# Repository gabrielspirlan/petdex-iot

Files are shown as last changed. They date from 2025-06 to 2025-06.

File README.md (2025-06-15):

<p align="center">
  Capa do Projeto
</p>

# Projeto IoT — Coleira Inteligente para Monitoramento de Animais

Bem-vindo! Este é o nosso projeto de Internet das Coisas (IoT), desenvolvido com o objetivo de criar um dispositivo inteligente que possa ser acoplado a qualquer coleira de animal — especialmente cães 🐶 e gatos 😺 — para monitorar continuamente dados de saúde e localização do pet, de forma semelhante às smartbands e smartwatches ⌚ utilizados por humanos.

<p align="center">
  Coleira PetDex
</p>

<p align="center">
  Coleira PetDex - 2
  Coleira PetDex - 3
</p>

## 🚩 Problema Identificado

Atualmente, existe uma carência de soluções acessíveis e contínuas para monitoramento de saúde em animais domésticos, especialmente aqueles que possuem doenças crônicas ou estão em tratamento. Além disso, muitos tutores enfrentam dificuldades ao perder seus pets e não conseguirem localizá-los facilmente.

## 💡 Solução Proposta

Criamos uma coleira inteligente equipada com sensores capazes de coletar dados vitais e de movimentação do animal. Através desses dados, conseguimos monitorar:

- **Batimentos cardíacos**
- **Nível de atividade física**
- **Localização em tempo real**

Com isso, é possível detectar comportamentos anormais e enviar alertas ao tutor caso o batimento cardíaco do animal esteja fora da faixa considerada normal, especialmente em relação ao seu nível de movimentação.

Todos os dados coletados são enviados automaticamente para um banco de dados via uma API que desenvolvemos, permitindo o acompanhamento em tempo real.

## 📦 Componentes Utilizados

- **ESP32 S3 Zero**: Microcontrolador com conectividade Wi-Fi e Bluetooth, ideal pelo seu tamanho compacto.
- **GY-MAX30102**: Sensor de batimentos cardíacos e oxímetro.
- **MPU6050**: Sensor de giroscópio e acelerômetro, responsável por captar a movimentação do animal.
- **NEO-6M**: Módulo GPS para rastreamento em tempo real.
- **LED RGB**: Indicadores visuais de status da coleira.

<p align="center">
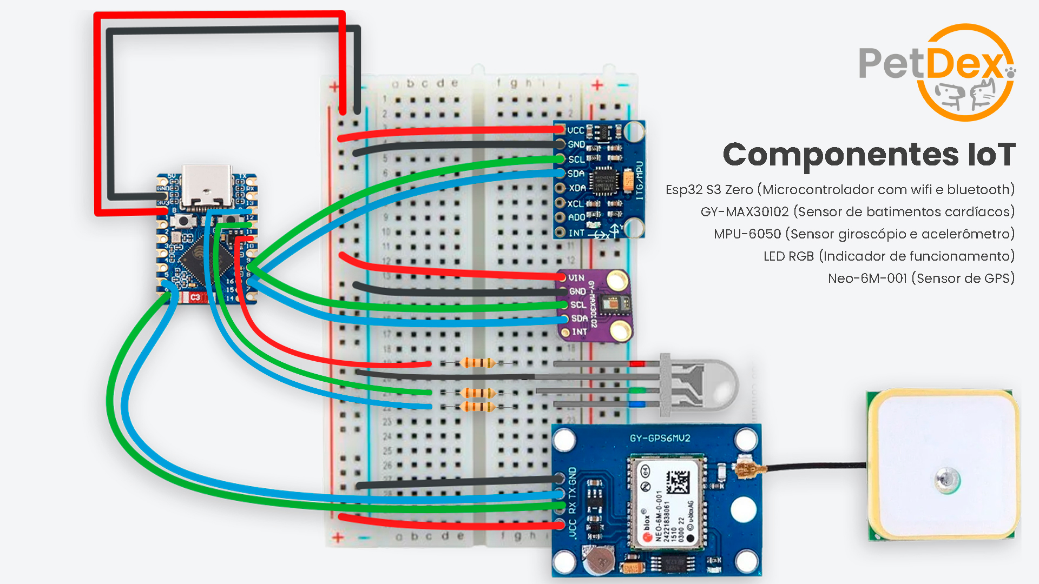
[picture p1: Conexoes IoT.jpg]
Conexões do IoT
  
</p>

## 🔧 Funcionamento dos LED indicador

- **LED Azul**: Tentativa de conexão com a rede Wi-Fi.
- **LED Verde**: Dados coletados com sucesso e enviados ao banco de dados.
- **LED Vermelho**:
  - Se acender após o LED azul: falha na conexão com o sensor de batimentos cardíacos.
  - Se acender rapidamente depois: falha no envio dos dados ao servidor.
- **LED Branco**: Falha na obtenção da hora atual. Nesse caso, recomenda-se reiniciar a coleira.

## 🧩 Projeto 3D

Também desenvolvemos um **suporte 3D personalizado** para fixar o circuito à coleira do animal de forma segura, confortável e discreta. O suporte foi projetado levando em consideração o bem-estar do pet e a praticidade de uso.

---

## 🤖 Programação

A programação do dispositivo foi feita utilizando a **IDE do Arduino**, com foco na simplicidade e eficiência.

Todo o funcionamento está concentrado em um único arquivo principal, localizado na pasta [`/code`](./code), onde o usuário pode configurar previamente as redes Wi-Fi às quais a coleira deve tentar se conectar.

### Funcionamento Geral do Código

- Ao iniciar, a coleira tenta se conectar automaticamente a uma das redes Wi-Fi configuradas.
- Após o sucesso da conexão, o sistema realiza a leitura dos **batimentos cardíacos** do animal por cerca de **15 segundos**, calculando uma **média** dos valores coletados.
- Em seguida, os dados de:
  - **Batimentos cardíacos**
  - **Movimentação** (acelerômetro e giroscópio)
  - **Localização GPS**

  são enviados para o **endpoint da nossa API** por meio de uma requisição HTTP.

Essa estrutura permite que os dados sejam atualizados em tempo real no banco de dados, possibilitando o monitoramento remoto da saúde e localização do animal.

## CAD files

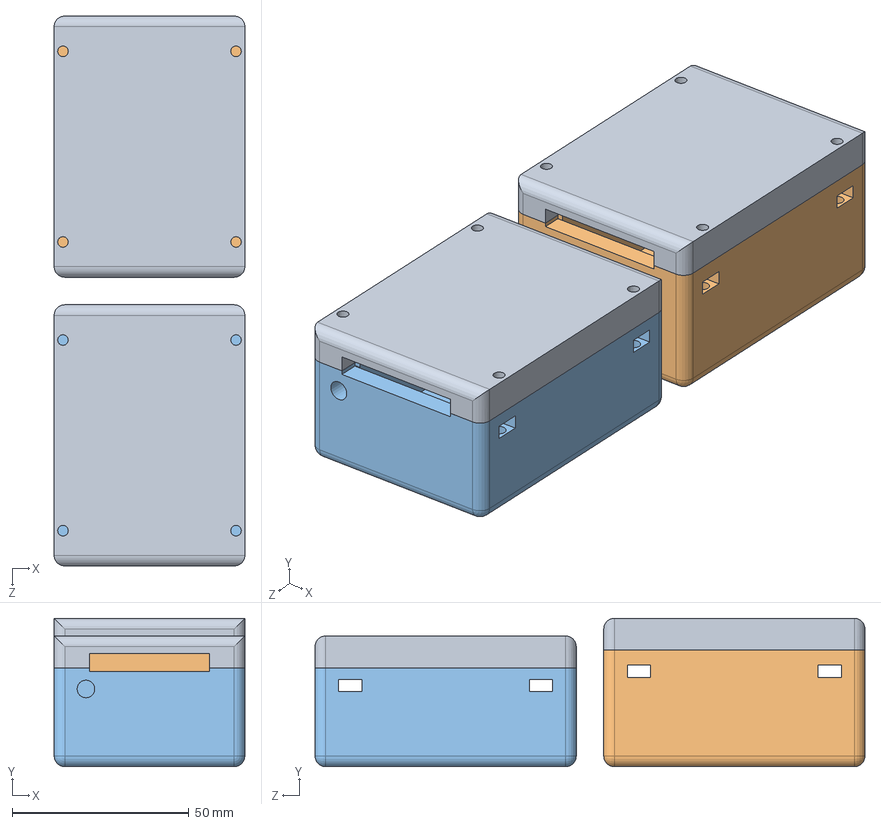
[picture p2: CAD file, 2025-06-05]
projeto-coleira/Montagem versões da coleira.SLDASM
54.0 x 42.0 x 155.8 mm
Coleira - Sensores (Ajustado v2)
Coleira - Sensores
Coleira - Tampa x 2

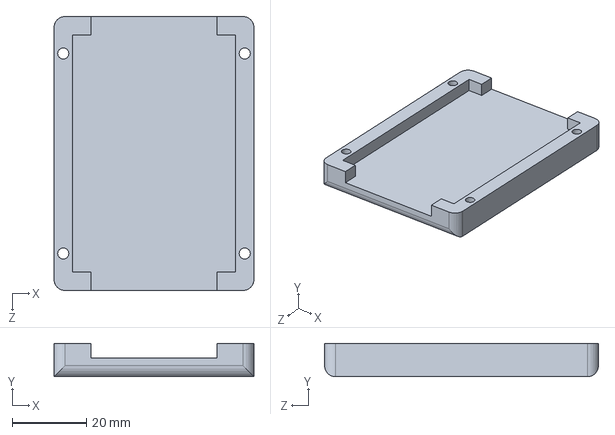
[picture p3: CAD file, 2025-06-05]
projeto-coleira/Coleira - Tampa.SLDPRT
54.0 x 9.00 x 74.0 mm

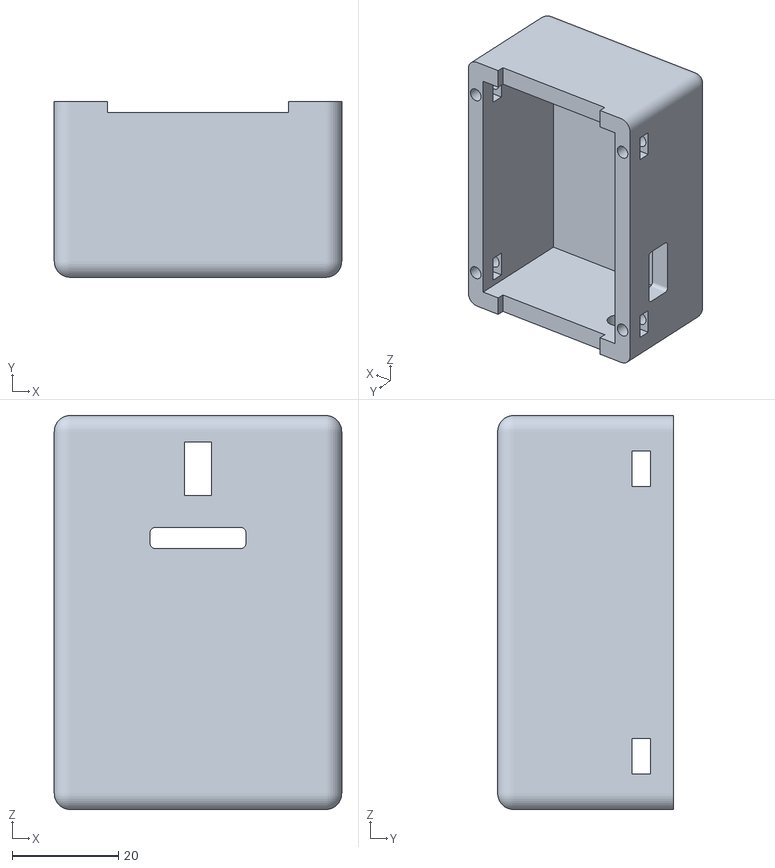
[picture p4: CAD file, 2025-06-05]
projeto-coleira/STL/Coleira - Tampa (Ajustado).STL
54.0 x 33.0 x 74.0

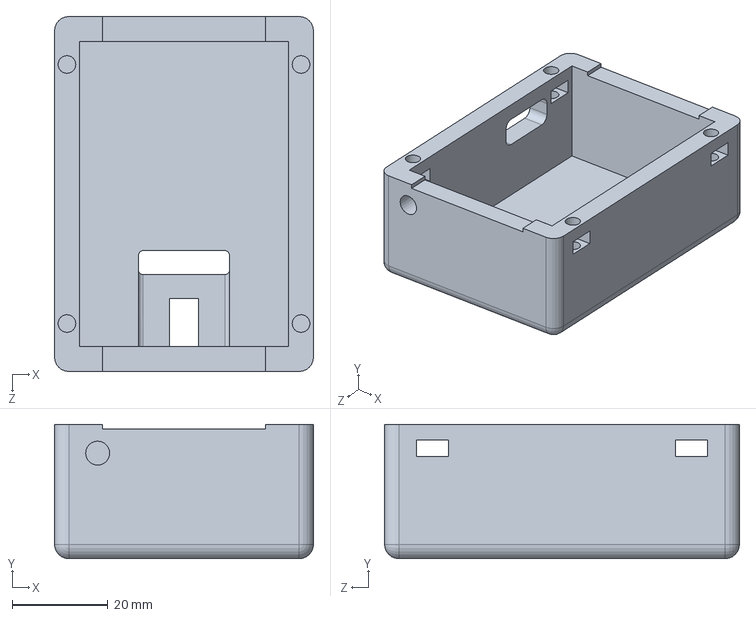
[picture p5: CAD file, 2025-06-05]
projeto-coleira/Coleira - Sensores (Ajustado v2).SLDPRT
54.0 x 28.0 x 74.0 mm

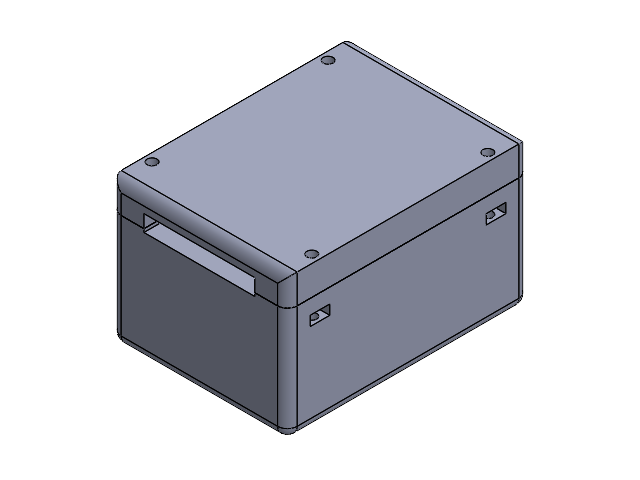
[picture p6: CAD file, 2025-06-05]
projeto-coleira/Montagem da Coleira.SLDASM
Coleira - sensores
ESP32-S3 Zero
tampa coleira

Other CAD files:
projeto-coleira/Coleira - Sensores (Ajustado).SLDPRT
projeto-coleira/Coleira - Sensores.SLDPRT
projeto-coleira/STL/Coleira - Sensores (Ajustado v2).STL
projeto-coleira/STL/Coleira - Sensores.STL
projeto-coleira/STL/Coleira - Tampa.STL

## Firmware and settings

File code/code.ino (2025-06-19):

#include <WiFi.h>
#include <HTTPClient.h>
#include "MAX30105.h"
#include "heartRate.h"
#include <TinyGPS++.h>
#include <MPU6050_tockn.h>
#include <Wire.h>
#include <WiFiManager.h>

WiFiManager wm;

#define RED_PIN 13
#define GREEN_PIN 12
#define BLUE_PIN 11

const char* serverName = "https://petdex-api-d75e.onrender.com";
const String coleiraId = "6819475baa479949daccea94";
const String animalId = "68194120636f719fcd5ee5fd";

MAX30105 particleSensor;

const long gmtOffset_sec = -3 * 3600;  // UTC-3 para horário de Brasília
const int daylightOffset_sec = 0;      // Sem horário de verão


const byte RATE_SIZE = 4;  //Increase this for more averaging. 4 is good.
byte rates[RATE_SIZE];     //Array of heart rates
byte rateSpot = 0;
long lastBeat = 0;  //Time at which the last beat occurred

float beatsPerMinute;
int beatAvg;
unsigned long leituraInicio = 0;
const unsigned long duracaoLeitura = 15000;
bool lendo = false;



// -------------- SENSOR DE GPS --------------

#define RXD2 5  // CONECTAR PORTA TX DO SENSOR
#define TXD2 6  // CONECTAR PORTA RX DO SENSOR

#define GPS_BAUD 9600
TinyGPSPlus gps;
// Create an instance of the HardwareSerial class for Serial 2
HardwareSerial gpsSerial(2);

// -------------- // --------------



// -------------- GIROSCÓPIO --------------
MPU6050 mpu6050(Wire);
// -------------- // --------------



void setup() {
  pinMode(RED_PIN, OUTPUT);
  pinMode(GREEN_PIN, OUTPUT);
  pinMode(BLUE_PIN, OUTPUT);
  Serial.begin(115200);
  delay(1000);

  wm.resetSettings();
  // ------------- WIFI -------------
  while (WiFi.status() != WL_CONNECTED) {
    digitalWrite(BLUE_PIN, HIGH);
    Serial.println("Configurar Wifi! Acesse a rede PetDex com a senha petdex1234 e selecione um Wifi para conexão.");
    wm.autoConnect("PetDex", "petdex1234");

    if (WiFi.status() == WL_CONNECTED) {
      Serial.println("Conectado com sucesso!");
    } else {
      Serial.println("Falha ao reconectar.");
    }
  }
  digitalWrite(BLUE_PIN, LOW);
  // -------------- // --------------


  // ------------- HORÁRIO ------------
  configTime(gmtOffset_sec, daylightOffset_sec, "pool.ntp.org");
  delay(2000);  // Espera a sincronização NTP

  struct tm timeinfo;
  while (!getLocalTime(&timeinfo)) {
    Serial.println("Erro ao obter hora");
    digitalWrite(RED_PIN, HIGH);
    digitalWrite(BLUE_PIN, HIGH);
    digitalWrite(GREEN_PIN, HIGH);
  }

  digitalWrite(RED_PIN, LOW);
  digitalWrite(BLUE_PIN, LOW);
  digitalWrite(GREEN_PIN, LOW);

  char isoTime[30];
  strftime(isoTime, sizeof(isoTime), "%Y-%m-%dT%H:%M:%SZ", &timeinfo);
  Serial.println("Hora atual:");
  Serial.println(isoTime);
  // -------------- // --------------




  // ------------- BATIMENTO CARDÍACO  ------------
  while (!particleSensor.begin(Wire, I2C_SPEED_FAST)) {
    digitalWrite(RED_PIN, HIGH);
    Serial.println("MAX30105 (Batimento Cardíaco) Não foi encontrado. ");
  }
  digitalWrite(RED_PIN, LOW);

  // Ligando as luzes do Batimetno Cardíaco para ajudar a medir
  particleSensor.setup();                     //Configure sensor with default settings
  particleSensor.setPulseAmplitudeRed(0x0A);  //Turn Red LED to low to indicate sensor is running
  particleSensor.setPulseAmplitudeGreen(0);   //Turn off Green LED
  // -------------- // --------------


  // -------------- GPS --------------
  gpsSerial.begin(GPS_BAUD, SERIAL_8N1, RXD2, TXD2);
  // -------------- // --------------




  // -------------- GIROSCÓPIO --------------
  Wire.begin();
  mpu6050.begin();
  mpu6050.calcGyroOffsets(true);
  // -------------- // --------------
}

void loop() {
  digitalWrite(GREEN_PIN, LOW);
  digitalWrite(BLUE_PIN, LOW);
  digitalWrite(RED_PIN, LOW);

  while (WiFi.status() != WL_CONNECTED) {
    digitalWrite(BLUE_PIN, HIGH);
    Serial.println("WiFi desconectado. Tentando reconectar...");
    wm.autoConnect("PetDex", "petdex1234");

    if (WiFi.status() == WL_CONNECTED) {
      Serial.println("Reconectado com sucesso!");
    } else {
      Serial.println("Falha ao reconectar.");
    }
  }

  digitalWrite(BLUE_PIN, LOW);

  double accX;
  double accY;
  double accZ;
  double angleX;
  double angleY;
  double angleZ;

  double latitude;
  double longitude;

  long leituraControle = 0;

  if (!lendo) {
    // Iniciar novo ciclo de leitura
    Serial.println("Iniciando leitura de batimentos por 10 segundos...");
    leituraInicio = millis();
    leituraControle = leituraInicio;
    lendo = true;
    beatAvg = 0;
    rateSpot = 0;
    lastBeat = 0;
    beatsPerMinute = 0;
  }

  // Enquanto estiver dentro do período de leitura
  while (millis() - leituraInicio <= duracaoLeitura) {
    long irValue = particleSensor.getIR();

    if (checkForBeat(irValue)) {
      long delta = millis() - lastBeat;
      lastBeat = millis();

      beatsPerMinute = 60 / (delta / 1000.0);

      if (beatsPerMinute < 255 && beatsPerMinute > 20) {
        rates[rateSpot++] = (byte)beatsPerMinute;
        rateSpot %= RATE_SIZE;

        beatAvg = 0;
        for (byte x = 0; x < RATE_SIZE; x++)
          beatAvg += rates[x];
        beatAvg /= RATE_SIZE;
      }
    }

    Serial.print("IR=");
    Serial.print(irValue);
    Serial.print(", BPM=");
    Serial.print(beatsPerMinute);
    Serial.print(", Avg BPM=");
    Serial.print(beatAvg);
    if (irValue < 50000 && millis() - leituraControle <= 20000) {
      // Espera até 20 segundos para o usuário colocar o dedo para realizar a leitura
      leituraInicio = millis();
      Serial.print(" Não está medindo batimentos");
    }
    Serial.println();
  }

  lendo = false;

  unsigned long start = millis();
  while (millis() - start < 1000) {
    while (gpsSerial.available() > 0) {
      gps.encode(gpsSerial.read());
    }
    if (gps.location.isUpdated()) {
      latitude = gps.location.lat();
      longitude = gps.location.lng();
    }
  }

  // -------------- GIROSCÓPIO --------------
  mpu6050.update();

  accX = mpu6050.getAccX();
  accY = mpu6050.getAccY();
  accZ = mpu6050.getAccZ();

  angleX = mpu6050.getGyroAngleX();
  angleY = mpu6050.getGyroAngleY();
  angleZ = mpu6050.getGyroAngleZ();

  // -------------- // --------------

  String timestamp = getISO8601Time();
  Serial.println("\n---------------------- LOCALIZACAO ----------------------");
  Serial.print("Latitude: ");
  Serial.print(latitude);
  Serial.print("  Longitude: ");
  Serial.println(longitude);
  Serial.println("\n-----------------------------------------------------------");
  if (beatAvg > 5) {
    enviarBatimento(beatAvg, timestamp);
  }
  if (((latitude > 1 && longitude > 1) || (latitude < -1 && longitude < -1)) && (latitude != 23.594131 && longitude != 23.93906)) {
    enviarLocalizacao(latitude, longitude, timestamp);
  }
  enviarMovimento(accX, accY, accZ, angleX, angleY, angleZ, timestamp);
}



String getISO8601Time() {
  struct tm timeinfo;
  if (!getLocalTime(&timeinfo)) {
    Serial.println("Erro ao obter hora");
    return "";
  }

  char isoTime[30];
  strftime(isoTime, sizeof(isoTime), "%Y-%m-%dT%H:%M:%S-03:00", &timeinfo);
  return String(isoTime);
}

void enviarBatimento(int media, String timestamp) {
  digitalWrite(GREEN_PIN, HIGH);
  digitalWrite(RED_PIN, LOW);
  digitalWrite(BLUE_PIN, LOW);
  String endpoint = String(serverName) + "/batimentos";
  HTTPClient http;
  String jsonData = "{";
  jsonData += "\"frequenciaMedia\": \"" + String(media) + "\", ";
  jsonData += "\"coleira\": \"" + coleiraId + "\", ";
  jsonData += "\"animal\": \"" + animalId + "\", ";
  jsonData += "\"data\": \"" + timestamp + "\"";
  jsonData += "}";

  Serial.println("Enviando Batimento:");
  Serial.println(jsonData);
  http.begin(endpoint);
  http.addHeader("Content-Type", "application/json");
  int httpResponseCode = http.POST(jsonData);
  Serial.print("POST status: ");
  Serial.println(httpResponseCode);
  if (httpResponseCode > 0) {
    String response = http.getString();
    Serial.println("Resposta: " + response);
  } else {
    digitalWrite(RED_PIN, HIGH);
    Serial.println("Erro ao enviar dados.");
    delay(500);
  }

  http.end();
}

void enviarLocalizacao(double latitude, double longitude, String timestamp) {
  digitalWrite(GREEN_PIN, HIGH);
  digitalWrite(RED_PIN, LOW);
  digitalWrite(BLUE_PIN, LOW);
  String endpoint = String(serverName) + "/localizacoes";
  HTTPClient http;
  String jsonData = "{";
  jsonData += "\"latitude\": \"" + String(latitude, 6) + "\", ";
  jsonData += "\"longitude\": \"" + String(longitude, 6) + "\", ";
  jsonData += "\"coleira\": \"" + coleiraId + "\", ";
  jsonData += "\"animal\": \"" + animalId + "\", ";
  jsonData += "\"data\": \"" + timestamp + "\"";
  jsonData += "}";

  Serial.println("Enviando Localização:");
  Serial.println(jsonData);
  http.begin(endpoint);
  http.addHeader("Content-Type", "application/json");
  int httpResponseCode = http.POST(jsonData);
  Serial.print("POST status: ");
  Serial.println(httpResponseCode);
  if (httpResponseCode > 0) {
    String response = http.getString();
    Serial.println("Resposta: " + response);
  } else {
    Serial.println("Erro ao enviar dados.");
    digitalWrite(RED_PIN, HIGH);
    Serial.println("Erro ao enviar dados.");
    delay(500);
  }

  http.end();
}

void enviarMovimento(double accX, double accY, double accZ, double angleX, double angleY, double angleZ, String timestamp) {
  digitalWrite(GREEN_PIN, HIGH);
  digitalWrite(RED_PIN, LOW);
  digitalWrite(BLUE_PIN, LOW);
  String endpoint = String(serverName) + "/movimentos";
  HTTPClient http;
  String jsonData = "{";
  jsonData += "\"acelerometroX\": \"" + String(accX) + "\", ";
  jsonData += "\"acelerometroY\": \"" + String(accY) + "\", ";
  jsonData += "\"acelerometroZ\": \"" + String(accZ) + "\", ";
  jsonData += "\"giroscopioX\": \"" + String(angleX) + "\", ";
  jsonData += "\"giroscopioY\": \"" + String(angleY) + "\", ";
  jsonData += "\"giroscopioZ\": \"" + String(angleZ) + "\", ";
  jsonData += "\"coleira\": \"" + coleiraId + "\", ";
  jsonData += "\"animal\": \"" + animalId + "\", ";
  jsonData += "\"data\": \"" + timestamp + "\"";
  jsonData += "}";

  Serial.println("Enviando Movimento:");
  Serial.println(jsonData);
  http.begin(endpoint);
  http.addHeader("Content-Type", "application/json");
  int httpResponseCode = http.POST(jsonData);
  Serial.print("POST status: ");
  Serial.println(httpResponseCode);
  if (httpResponseCode > 0) {
    String response = http.getString();
    Serial.println("Resposta: " + response);
  } else {
    Serial.println("Erro ao enviar dados.");
    digitalWrite(RED_PIN, HIGH);
    Serial.println("Erro ao enviar dados.");
    delay(500);
  }

  http.end();
}
